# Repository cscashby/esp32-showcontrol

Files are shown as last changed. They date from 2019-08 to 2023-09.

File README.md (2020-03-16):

# esp32-showcontrol
Showcontrol with an ESP32.

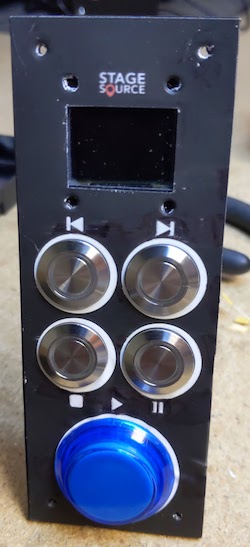
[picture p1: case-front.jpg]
Control box front


## Overview

The box is PoE powered (if you use a suitable board, I highly recommend the [ESP32-PoE-ISO](https://www.olimex.com/Products/IoT/ESP32/ESP32-POE-ISO/open-source-hardware) which has adequate isolation for the network port, or can be powered using a Micro USB connector and will support WiFi (though this is not recommended for production use for obvious reasons, and hasn't yet been implemented).

The current design allows for Go, Stop, Pause, Next and Previous buttons, and a Jack terminated footswitch (likely mapped to Go, obviously).

It communicates via one ore more QLab machines via OSC over UDP and (not yet implemented) will have a web interface to configure QLab machine IP address, button mapping, display layout (maybe!).

The control box has a display (The first iteration has a 0.94-0.96" screen which can display 3-4 lines of text) and will show the currently playing and next cue, although this is customizable, as well as a 'heartbeat' indicator to show QLab is running and accepting network traffic.

The good, the bad and the ugly of the creation process are [documented in this photo album](https://photos.app.goo.gl/oM8NKtMR5yHytawS9).

[You can see the current version in action here](https://youtu.be/rc1Ihym0WEM?fbclid=IwAR3Ep9oDbkkQK5u_lBfwsQPnMIx6SqTjP9gkLyZevePxKnQPljE5RvLPe-E).

## Known issues

Check out the [GitHub issues page](https://github.com/cscashby/esp32-showcontrol/issues)

Key show-stopper(s) right now:
- [Keys auto-repeat](https://github.com/cscashby/esp32-showcontrol/issues/5)

## Wiring

The box wiring is currently soldered wires directly onto pushbuttons and LEDs, and soldered onto the OLED board.  [Pinouts are documented in a separate file for the ESP32-POE-ISO board](https://github.com/cscashby/esp32-showcontrol/blob/master/esp32-poe-iso-connections.md).

## Development

### IDE Setup

To set up the [Arduino IDE](https://www.arduino.cc/en/main/software) to develop on the [ESP32-PoE-ISO](https://www.olimex.com/Products/IoT/ESP32/ESP32-POE-ISO/open-source-hardware) board, you will need the drivers from the manufacturer's website.

You will also need the ESP32 default board set up through Board Manager within the Arduino IDE, [using these instructions](https://github.com/espressif/arduino-esp32/blob/master/docs/arduino-ide/boards_manager.md).

In addition, you will need to install the following list of libraries, either from Libraries manager (version given at time of writing), or as ZIP/Folder from the URLs given:

- SSD_13XX (Submodule)
- ArduinoOSC (Submodule)
- ArduinoJson (6.14.1)

For Submodules, don't forget to download them after cloning with `git submodule update --init`

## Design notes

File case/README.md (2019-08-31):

# esp32-showcontrol case

Case for show control based on ESP32-PoE-ISO board.

Dimensions: 50w x 135d x 54h
Case holes: 2mm in base (for self taps) 4mm top (clearance holes), countersunk
Protrusion from top cover to support / hold PCB secure, should rest on end of ESP32 module itself

Switches for go/stop (bottom pair) with 16mm diameter drill, but flats to 15mm at sides
Switches for prev/next (top pair) with 16mm diameter drill only
Adafruit 0.96" display with 2mm clearance / 2mm thick inset for 1-2mm thick clear perspex

Source for 3d models:
* Base: https://www.tinkercad.com/things/kWZmtJTIC6w-esp32-poe-gobutton
* Top
  * https://www.tinkercad.com/things/iRHtitwJItW-esp32-gobutton-top-bfb-diymore-version
    * This is the version for a DIYmore 0.95" 90x64 screen. If this doesn't have enough pixels the Adafruit 0.96" may be better.
    * NOTE when building this I realised that some of the screens I have have the display stuck in a slightly lower-than-marked position on the board. Unfortunately I did the design using one of these screens not the ones that are positioned correctly, so if you are building this, move the display around according to your ACTUAL screen before printing!
  * https://www.tinkercad.com/things/iRHtitwJItW-esp32-gobutton-top-bfb-adafruit-version
    * This is the version for an Adafruit 160x80 display with SD card. It's a bit more expensive, but has more pixels, which is nice.
  * Both of these are 'BFB' versions (Big ... Button) which I prefer as it's fairly obvious what to hit for 'go'...
  * I've left the old version here for posterity - note that the board standoff pole is NOT in the right place in this version, nor is the screen hole the right size (🤦): https://www.tinkercad.com/things/igH9JtvcPgK-esp32-gobutton-top-old-version

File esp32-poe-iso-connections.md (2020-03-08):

# Pinouts for ESP32-PoE-ISO board

Reference: [ESP32-PoE-ISO-Rev B Datasheet](https://github.com/OLIMEX/ESP32-POE-ISO/blob/master/HARDWARE/ESP32-PoE-ISO-Rev.B/ESP32-PoE-ISO_Rev_B.pdf)

| EXT1 pin | Function | Connected to | Top Case Wire Colour |
| :---: | :--- | :--- | :--- |
| 1 | +5v | | Orange |
| 2 | +3.3v | | |
| 3 | GND | | Brown |
| 4 | ESP_EN | | |
| 5 | GPIO0 | LED_GO | White |
| 6 | GPIO1 | JACK_IN | Grey |
| 7 | GPIO2 | LCD_SDA | Purple |
| 8 | GPIO3 | LCD_RST | Blue |
| 9 | GPIO4 | LCD_DC | Green |
| 10 | GPIO5 | LCD_CS | Yellow |

| EXT2 pin | Function | Connected to | Top Case Wire Colour |
| :---: | :--- | :--- | :--- |
| 1 | GPI39 | BTN_NEXT | Yellow |
| 2 | GPI36 | BTN_PREV | Green |
| 3 | GPI35 | BTN_STOP | Blue |
| 4 | GPI34 | BTN_PAUSE | Purple |
| 5 | GPIO33 | BTN_GO | Grey |
| 6 | GPIO32 | LED_NEXT | White |
| 7 | GPIO16 | LED_PREV | Black |
| 8 | GPIO15 | LED_STOP | Brown |
| 9 | GPIO14 | LCD_SCL | Orange |
| 10 | GPIO13 | LED_PAUSE | Red |

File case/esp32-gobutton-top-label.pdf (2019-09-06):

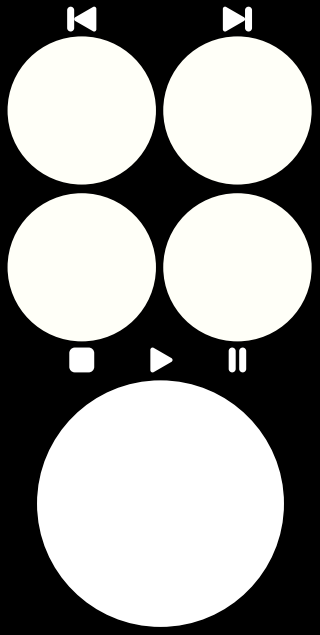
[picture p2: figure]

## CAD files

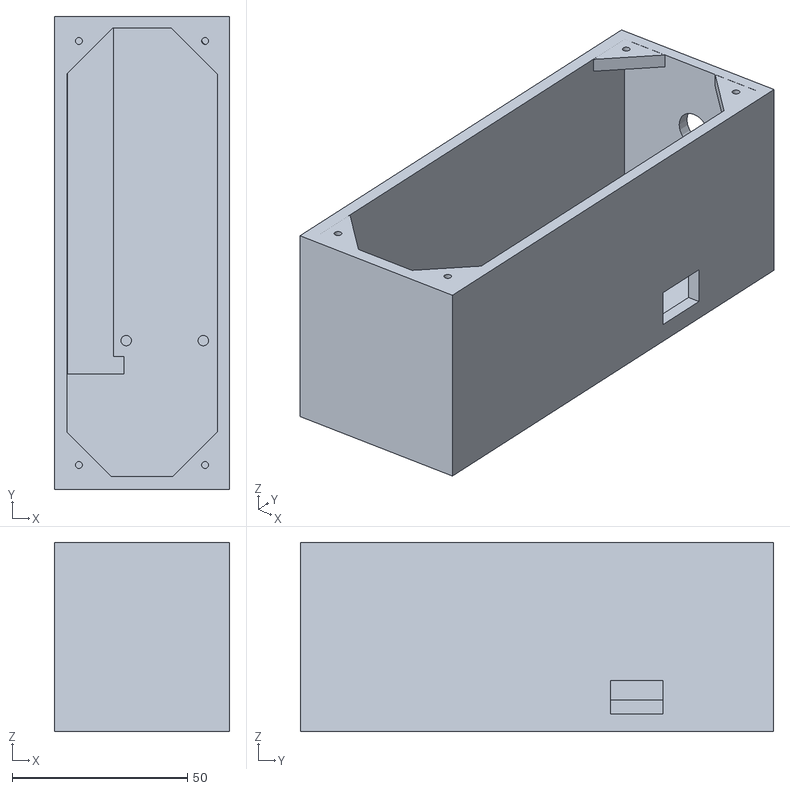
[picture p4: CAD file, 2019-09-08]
case/esp32-gobutton-base.stl
50.0 x 135.0 x 54.0

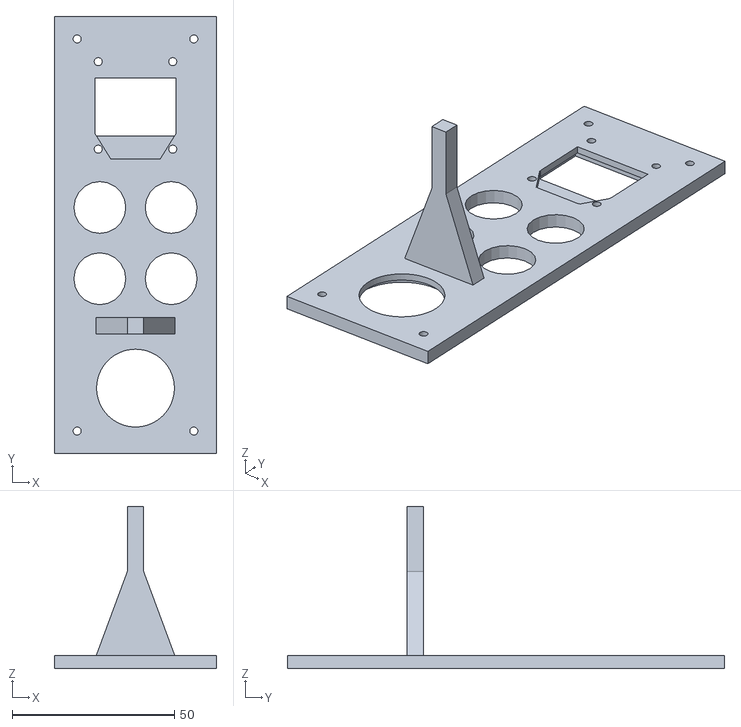
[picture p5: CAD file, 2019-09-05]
case/esp32-gobutton-top-diymore.stl
50.0 x 135.0 x 50.0

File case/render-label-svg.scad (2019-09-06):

projection() import("./esp32-gobutton-top-diymore.stl");

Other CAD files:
case/esp32-gobutton-top-adafruit.stl

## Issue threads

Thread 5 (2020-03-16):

Remove key auto-repeat

cscashby, 2020-03-16:
Currently pressing e.g. prev/next buttons for two long results in a double action. This needs to be disabled and ideally configurable.

cscashby, 2020-03-22:
Unfortunately this isn't sufficient. Need to work out a new debounce scheme. The problem is mainly that a long press results in a RISING signal then bounce BACK - which needs to be detected and filtered.

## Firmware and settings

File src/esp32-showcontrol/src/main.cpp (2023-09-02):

#include <Arduino.h>
#include <ETH.h>
#include "Display.h"
#include "Network.h"
#include "Config.h"
#include "Button.h"
#include "const.h"

#include <esp_log.h>

Display d = Display();

hw_timer_t *heartbeatTimer = NULL;
hw_timer_t *pollTimer = NULL;
portMUX_TYPE timerMux = portMUX_INITIALIZER_UNLOCKED;

bool postInitDone = false;

void IRAM_ATTR hearbeatTimerISR() {
  if( Config::mainLoopStarted ) { 
    OSC::heartbeat();
  }
}

void IRAM_ATTR pollTimerISR() {
  for (unsigned i=0; i < Config::getConfig().buttons.size(); i++) {
    Config::getConfig().buttons.at(i).poll();
  }
}

void setup() {
  Serial.begin(460800);
  esp_log_level_set("*", ESP_LOG_DEBUG);

  // No OSC yet - we wait for a button press
  Config::mainLoopStarted = false;

  d.begin();
  Network::begin(&d);
  for (unsigned i=0; i < Config::getConfig().buttons.size(); i++) {
    Config::getConfig().buttons.at(i).begin();
  }

  pollTimer = timerBegin(POLL_TIMER, 80, true);
  timerAttachInterrupt(pollTimer, &pollTimerISR, true);
  timerAlarmWrite(pollTimer, Config::getConfig().timers.poll_us, true);
  timerAlarmEnable(pollTimer);  
}

void doPostInit() {
  d.clearTextArea();

  OSC::begin(&d);
  
  heartbeatTimer = timerBegin(HEARTBEAT_TIMER, 80, true);
  timerAttachInterrupt(heartbeatTimer, &hearbeatTimerISR, true);
  timerAlarmWrite(heartbeatTimer, Config::getConfig().timers.heartbeat_us, true);
  timerAlarmEnable(heartbeatTimer);    
  
  postInitDone = true;
}

void loop() {
  Network::loop();
  
  if( Config::mainLoopStarted ) { 
    if( !postInitDone )
      doPostInit();
    
    OSC::loop();
  }
}

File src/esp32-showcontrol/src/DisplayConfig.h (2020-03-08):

#ifndef DisplayConfig_h
#define DisplayConfig_h

// Display variables (all prefix LCD_)
#define LCD_SCL   14 //default / hard wired so unused
#define LCD_SDA   2  //default / hard wired so unused
#define LCD_CS    5  
#define LCD_DC    4 
#define LCD_RST   3

#define LCD_WIDTH 96
#define LCD_HEIGHT 64

#define TEXTAREA_X 0
#define TEXTAREA_Y 0
#define TEXTAREA_WIDTH 96
#define TEXTAREA_HEIGHT 64

#define LCD_BG_COLOR BLACK

#define LINE_LENGTH 14

const unsigned char LCD_HEART [] PROGMEM = {
  // 'h, 16x16px
  0x00, 0x00, 0x00, 0x00, 0x3c, 0x3c, 0x42, 0x42, 0x83, 0xc3, 0x80, 0x03, 0xc0, 0x03, 0xc0, 0x03, 
  0x20, 0x04, 0x30, 0x0c, 0x18, 0x18, 0x04, 0x20, 0x02, 0x40, 0x03, 0x80, 0x00, 0x00, 0x00, 0x00
};
#define LCD_HEART_WIDTH 16
#define LCD_HEART_HEIGHT 16
#define LCD_HEART_X LCD_WIDTH-LCD_HEART_WIDTH
#define LCD_HEART_Y 0
#define LCD_HEART_COLOR GREEN
const unsigned char LCD_BROKENHEART [] PROGMEM = {
  // 'bh, 16x16px
  0x00, 0x00, 0x1c, 0x78, 0x76, 0xde, 0x42, 0xca, 0x83, 0x47, 0x87, 0x63, 0x84, 0xe1, 0xc6, 0x83, 
  0x43, 0x82, 0x61, 0x86, 0x31, 0x8c, 0x18, 0x98, 0x0c, 0x30, 0x03, 0xc0, 0x01, 0x80, 0x00, 0x00
};
#define LCD_BROKENHEART_WIDTH 16
#define LCD_BROKENHEART_HEIGHT 16
#define LCD_BROKENHEART_X LCD_WIDTH-LCD_BROKENHEART_WIDTH
#define LCD_BROKENHEART_Y 0
#define LCD_BROKENHEART_COLOR RED

#endif

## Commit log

2019-07-22 Adding first demo for buttons / LEDs
2019-08-11 Changing pin due to SSD_13XX compat issue
2019-08-26 Adding case design (base)
    [esp32-gobutton-base.stl]
2019-08-26 Added hole for footswitch
    [esp32-gobutton-base.stl]
2019-08-26 Enlarged box for display and buttons to fit easier
    [esp32-gobutton-base.stl]
2019-08-26 Rename to remove case for case
    [esp32-gobutton-base.stl]
2019-08-26 Create README for case folder
    Includes tinkercad links etc
2019-08-26 Adding detail on drill holes, etc.
2019-08-26 Adding mounting holes to LCD and realigning to fit
    [esp32-gobutton-top.stl]
2019-08-27 New version of top case with BFB for 'go', and proper (hopefully) sizing
    [esp32-gobutton-top.stl]
2019-08-29 New case for DIYmore display, and settings to match
    [esp32-gobutton-top diymore.stl, esp32-gobutton-top-adafruit.stl]
2019-08-30 New base with moved jack socket
    [esp32-gobutton-base.stl]
2019-08-31 Adding pinout and wiring list
2019-08-31 Adding pause button
2019-09-01 Framework now includes networking support / web server, etc. No OSC functionality yet in the refactored code
2019-09-05 Updated case top to include smaller countersink holes
    [esp32-gobutton-top diymore.stl]
2019-09-06 Adding case artwork and image showing case current state
    [esp32-gobutton-top-diymore.stl, render-label-svg.scad]
2019-09-06 Adding network case statement (ethernet isn't currently functional with WiFi) Renaming case STL file
    [esp32-gobutton-top diymore.stl]
2019-09-06 Button functionality and tidied up some timers
2019-09-07 Externalised timers to JSON Tidied up use of config.h to avoid circular dependencies (i.e. put include for it in .cpp files)
    [Button.cpp, Config.cpp, Network.cpp]
2019-09-07 Adding OSC framework - No ability yet to respond / subscribe - No regular heartbeat
2019-09-07 Decided to remove AutoConnect - it doesn't play nice with ISRs and timers, so it's worth home spinning a simpler config for wifi, etc.
    [Network.cpp]
2019-09-08 Updated base box design to add sideways block - enlarged slightly
    [esp32-gobutton-base.stl]
2019-09-08 Update esp32-poe-iso-connections.md
    Typo fix
2019-09-09 Update esp32-poe-iso-connections.md
    New colours
2020-03-08 Working with current playbackPosition display, no playing cue display yet
2020-03-08 Fixing wrong cases, etc
    [Config.cpp]
2020-03-08 First effort at config page (not working)
    [Network.cpp]
2020-03-09 Added invert capability for annoying LEDs that have wrong polarity
    [Button.cpp, Config.cpp]
2020-03-15 Added board setup &c
2020-03-15 Moving TFT start code to avoid power-on failure under POE
2020-03-16 Adding initialisation for debounce timeout which should fix Issue #5
    [Button.cpp]
2023-08-28 Fixing for new AndroidOSC -compiles but not tested
    [Config.cpp, OSC.cpp]
2023-08-28 Updated for test machine, and fixed network status
    [Network.cpp]
2023-09-02 Not working current updates
    [OSC.cpp, main.cpp]
